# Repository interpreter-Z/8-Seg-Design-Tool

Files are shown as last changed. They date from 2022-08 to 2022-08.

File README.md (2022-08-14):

# 8-Seg-Design-Tool
A PCB click-toy that you can use to design 8-segment display patterns (or kill time with)

This repo houses a simple hardware project for a custom PCB designed with KiCad 6.0.

For more information on the following items, please refer to:
- Final product:      README.pdf
- PCB source files:   8 Seg Design Tool/
- Gerber files:       gerbers/
- Components:         datasheet/
- Purchase Links:     BOM.csv

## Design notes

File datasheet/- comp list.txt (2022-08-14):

8 Seg Display (38.10): 	https://www.digikey.com/en/products/detail/chromeled/CDSA15R1W/13166840
	      (20.32):	https://www.digikey.com/en/products/detail/kingbright/SA08-11EWA/3084462
Toggle Botton (SPST): 	https://www.digikey.com/en/products/detail/judco-manufacturing-inc/50-0015-00/307997
	      (DPST):	https://www.digikey.com/en/products/detail/c-k/PVA1EEH11-2NV2/417713
LED (15mcd):		https://www.digikey.com/en/products/detail/bivar-inc/SM1206HC/3095545
    (4.5mcd):		https://www.digikey.com/en/products/detail/osram-opto-semiconductors-inc/LS-L29K-G1J2-1-Z/1227979
Coin Cell Holder:	https://www.digikey.com/en/products/detail/mpd-memory-protection-devices/BH800S/221549
Coin Cell:		https://www.digikey.com/en/products/detail/murata-electronics/CR2025/9558424
Resistor:		https://www.digikey.com/en/products/detail/stackpole-electronics-inc/RMCF1206JT150R/1757485
Toggle Switches:	https://www.digikey.com/en/products/detail/nkk-switches/B13JB/4507647
PCB Connector:		https://www.digikey.com/en/products/detail/w%C3%BCrth-elektronik/613010143121/2508632

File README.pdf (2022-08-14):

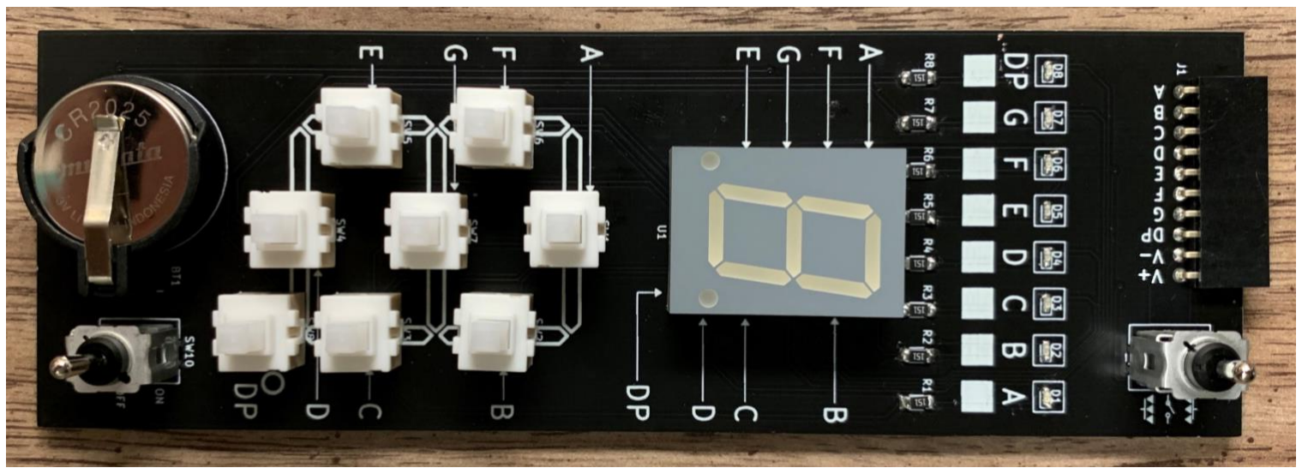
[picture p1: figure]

## facilitate design of 8-segment illumination pattern

(Or just a click-toy to kill time with)

# 8-Segment Display Design Tool

## Features:

Display: • LED x8 • 8-segment display x1

Display Control: • Toggle push switch (DPST) x8 • Switches are arranged to mirror 7-segment display pattern

(*or 8

-segment if you count the decimal)

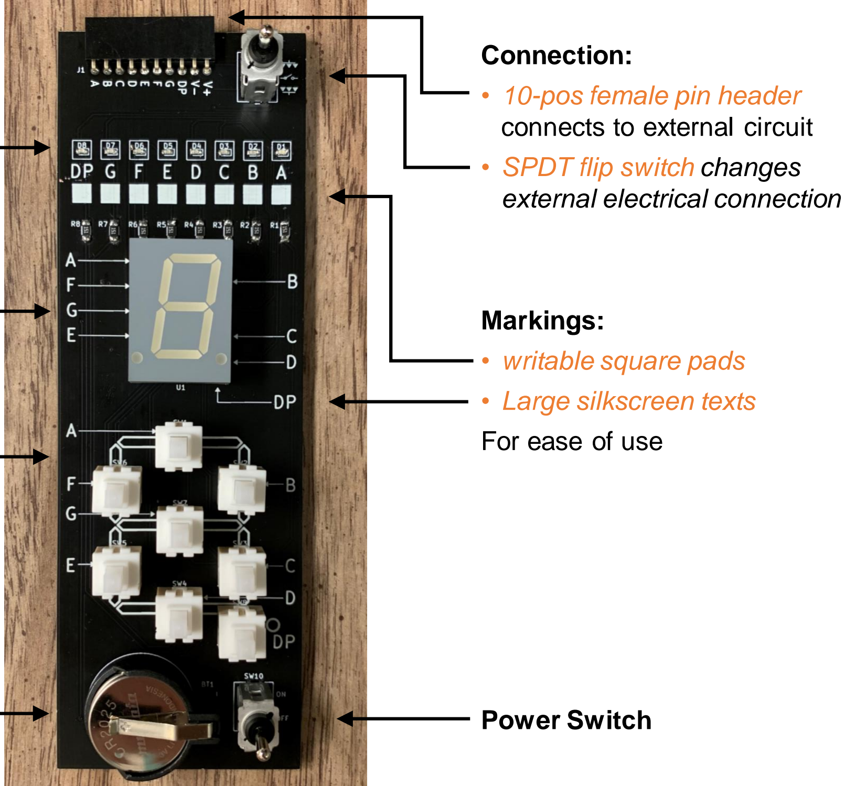
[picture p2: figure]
For ease of use; Connection: • 10-pos female pin header; connects to external circuit; • SPDT flip switch changes external electrical connection; Power Switch

Markings: • writable square pads • Large silkscreen texts

Power: • 3V Coin Cell x2 = 6V

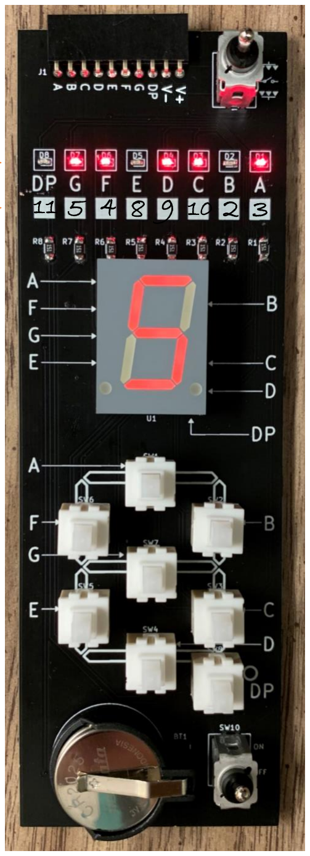
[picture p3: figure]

## Function 1: Map Segment to Pin

1. On the white squares, (using a marker,) write down the pinout of each segment of the display that is specific to your project
2. Press to toggle the push switches such that you see your desired pattern on the 8-segment display
3. Check the row of LED to have a quick view of which segments are illuminated. NOTE that the segment designators are sequenced from RIGHT TO LEFT
4. Find the pinout of the illuminated segments by referring to your notes on the white squares and program your project code accordingly. Depending on the complexity of your code, you might not need to do this step.

1

3
4

## Function 2: Switching External Display

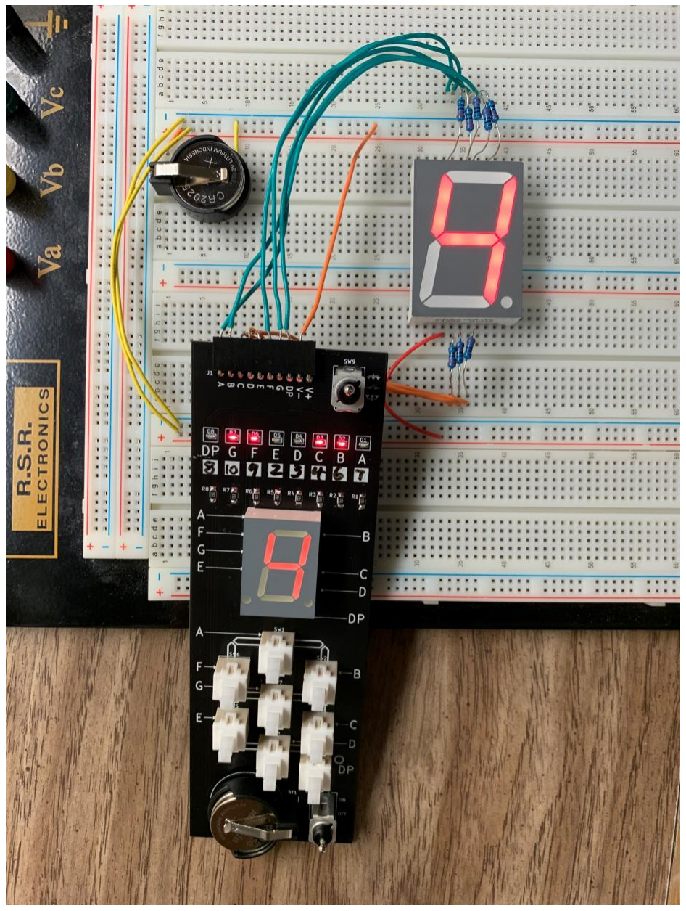
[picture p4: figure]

The PCB can be connected to an external display and power source to control that display (even when the PCB is powered off).

The external display is controlled the same way as the on-board display. NOTE that external resistors are required for the external display

On J1, connect the pins to their corresponding segments (A~G and DP) on the external display.

Depending on the type of external display, the external power supply need to be connected to the PCB in different ways.

## Function 2: Switching External Display (cont.)

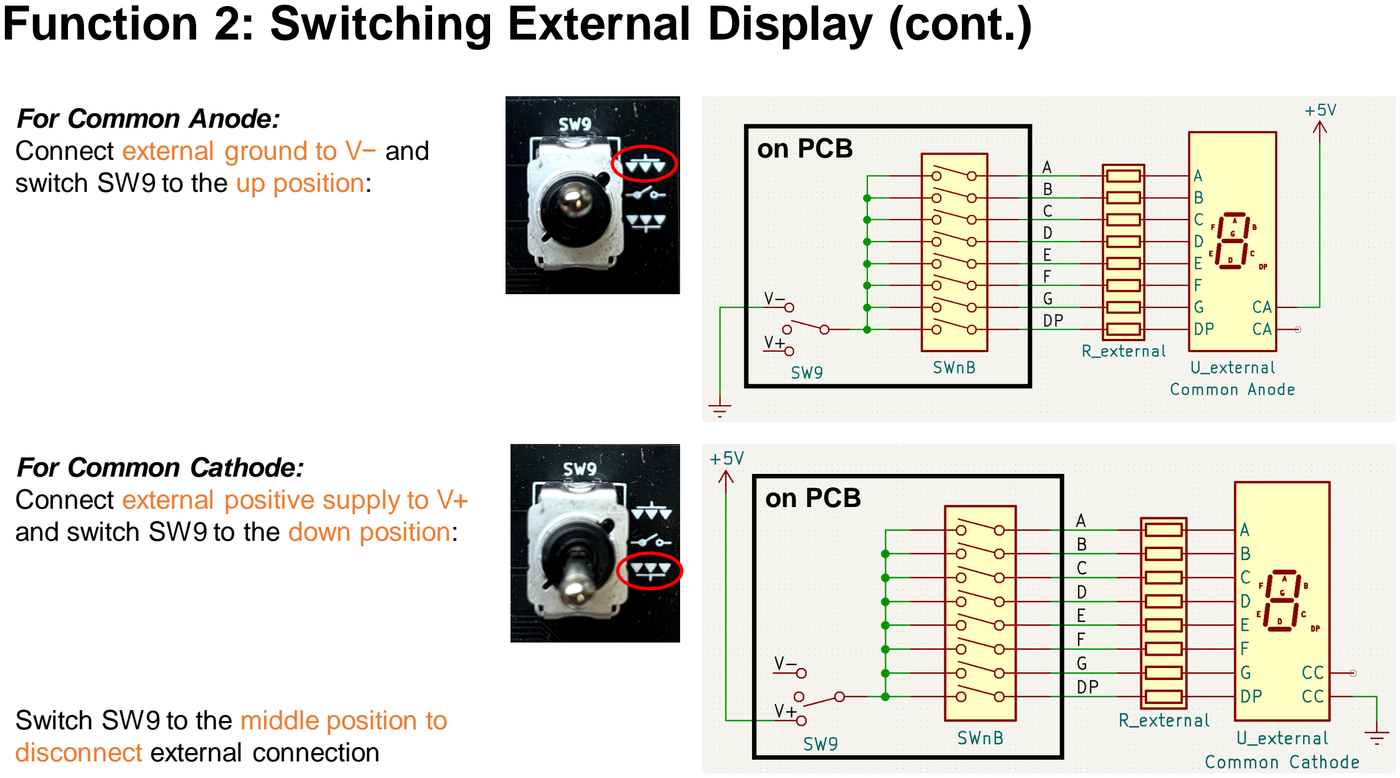
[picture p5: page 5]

on PCB

on PCB

For Common Anode:
Connect external ground to V− and switch SW9 to the up position:

For Common Cathode:
Connect external positive supply to V+ and switch SW9 to the down position:

Switch SW9 to the middle position to disconnect external connection

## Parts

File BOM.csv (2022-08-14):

Source: | D:\SPTS_A\MyWorks\KiCad\8 Seg Design Tool\8 Seg Design Tool\8 Seg Design Tool.kicad_sch
Date: | 6/13/2022 00:46
Tool: | Eeschema (6.0.0)
Generator: | D:\SPTS_B\Applications\KiCad\6.0\bin\scripting\plugins/bom_csv_grouped_by_value.py
Component Count: | 29
Collated Components:
Num Duplicates | 2 |  |  |  |  | (At 1 Dup) |  | (At Dup Qty)
Item | Qty | Dup Qty | Reference(s) | Value | MPN | Unit Price | Total Price | Unit Price | Total Price | URL
1 | 1 | 2 | BT1 | BH800S | BH800S | $1.41 | $1.41 | $1.41 | $2.82 | https://www.digikey.com/en/products/detail/mpd-memory-protection-devices/BH800S/221549
2 | 8 | 16 | D1, D2, D3, D4, D5, D6, D7, D8 | RED | LS L29K-G1J2-1-Z | $0.41 | $3.28 | $0.32 | $5.14 | https://www.digikey.com/en/products/detail/osram-opto-semiconductors-inc/LS-L29K-G1J2-1-Z/1227979
3 | 1 | 2 | J1 | Conn_01x10 | 6.1301E+11 | $0.95 | $0.95 | $0.95 | $1.90 | https://www.digikey.com/en/products/detail/w%C3%BCrth-elektronik/613010143121/2508632
4 | 8 | 16 | R1, R2, R3, R4, R5, R6, R7, R8 | 150 | RMCF1206JT150R | $0.10 | $0.80 | $0.03 | $0.45 | https://www.digikey.com/en/products/detail/stackpole-electronics-inc/RMCF1206JT150R/1757485
5 | 8 | 16 | SW1, SW2, SW3, SW4, SW5, SW6, SW7, SW8 | SW_DPST_x2 | PVA1EEH11.2NV2 | $1.65 | $13.20 | $1.48 | $23.63 | https://www.digikey.com/en/products/detail/c-k/PVA1EEH11-2NV2/417713
6 | 2 | 4 | SW9, SW10 | B13JB | B13JB | $4.92 | $9.84 | $4.92 | $19.68 | https://www.digikey.com/en/products/detail/nkk-switches/B13JB/4507647
7 | 1 | 2 | U1 | SA08-11EWA | CDSA15R1W | $2.98 | $2.98 | $2.98 | $5.96 | https://www.digikey.com/en/products/detail/chromeled/CDSA15R1W/13166840
8 | 1 | 10 | - | - | CR2025 | $0.32 | $0.32 | $0.26 | $2.64 | https://www.digikey.com/en/products/detail/murata-electronics/CR2025/9558424
 |  |  |  |  |  | Total: | $32.78 | Total: | $62.22

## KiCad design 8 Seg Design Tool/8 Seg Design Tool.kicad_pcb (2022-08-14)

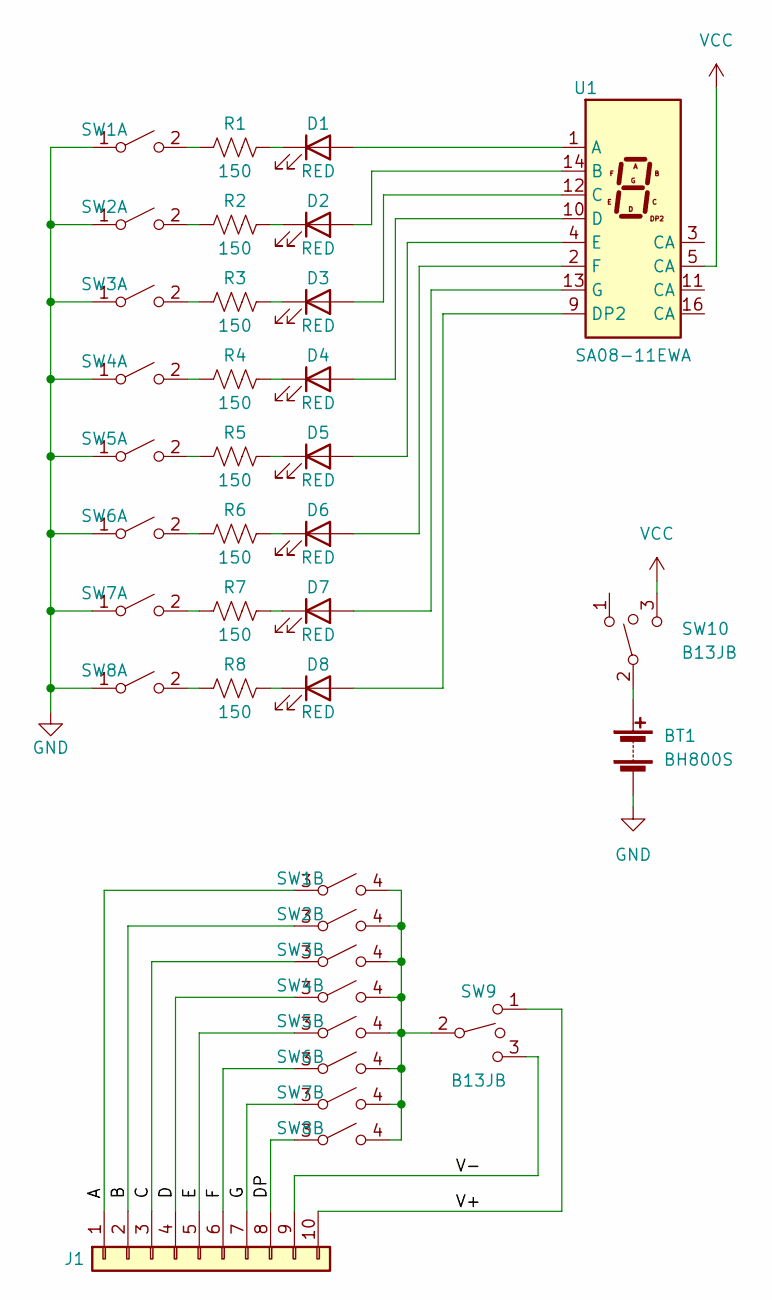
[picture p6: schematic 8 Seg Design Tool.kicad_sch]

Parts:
BT1: BH800S
D1, D2, D3, D4, D5, D6, D7, D8: RED; LS-L29K-G1J2-1-Z
J1: Conn_01x10; 613010143121
R1, R2, R3, R4, R5, R6, R7, R8: 150; RMCF1206JT150R
SW1, SW2, SW3, SW4, SW5, SW6, SW7, SW8: SW_DPST_x2; PVA1EEH11-2NV2-PDIP
SW9, SW10: B13JB
U1: SA08-11EWA; SA08-11EWA-PDIP

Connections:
GND: BT1.2 (-), SW1.1 (A), SW2.1 (A), SW3.1 (A), SW4.1 (A), SW5.1 (A), SW6.1 (A), SW7.1 (A), SW8.1 (A)
unnamed: BT1.1 (+), SW10.2 (B)
unnamed: D1.1 (K), R1.2
unnamed: D1.2 (A), U1.1 (A)
unnamed: D2.1 (K), R2.2
unnamed: D2.2 (A), U1.14 (B)
unnamed: D3.1 (K), R3.2
unnamed: D3.2 (A), U1.12 (C)
unnamed: D4.1 (K), R4.2
unnamed: D4.2 (A), U1.10 (D)
unnamed: D5.1 (K), R5.2
unnamed: D5.2 (A), U1.4 (E)
unnamed: D6.1 (K), R6.2
unnamed: D6.2 (A), U1.2 (F)
unnamed: D7.1 (K), R7.2
unnamed: D7.2 (A), U1.13 (G)
unnamed: D8.1 (K), R8.2
unnamed: D8.2 (A), U1.9 (DP2)
unnamed: J1.1, SW1.3 (A)
unnamed: J1.2, SW2.3 (A)
unnamed: J1.3, SW3.3 (A)
unnamed: J1.4, SW4.3 (A)
unnamed: J1.5, SW5.3 (A)
unnamed: J1.6, SW6.3 (A)
unnamed: J1.7, SW7.3 (A)
unnamed: J1.8, SW8.3 (A)
unnamed: J1.9, SW9.3 (C)
unnamed: J1.10, SW9.1 (A)
unnamed: R1.1, SW1.2 (B)
unnamed: R2.1, SW2.2 (B)
unnamed: R3.1, SW3.2 (B)
unnamed: R4.1, SW4.2 (B)
unnamed: R5.1, SW5.2 (B)
unnamed: R6.1, SW6.2 (B)
unnamed: R7.1, SW7.2 (B)
unnamed: R8.1, SW8.2 (B)
unnamed: SW1.4 (B), SW2.4 (B), SW3.4 (B), SW4.4 (B), SW5.4 (B), SW6.4 (B), SW7.4 (B), SW8.4 (B), SW9.2 (B)
VCC: SW10.3 (C), U1.5 (CC)

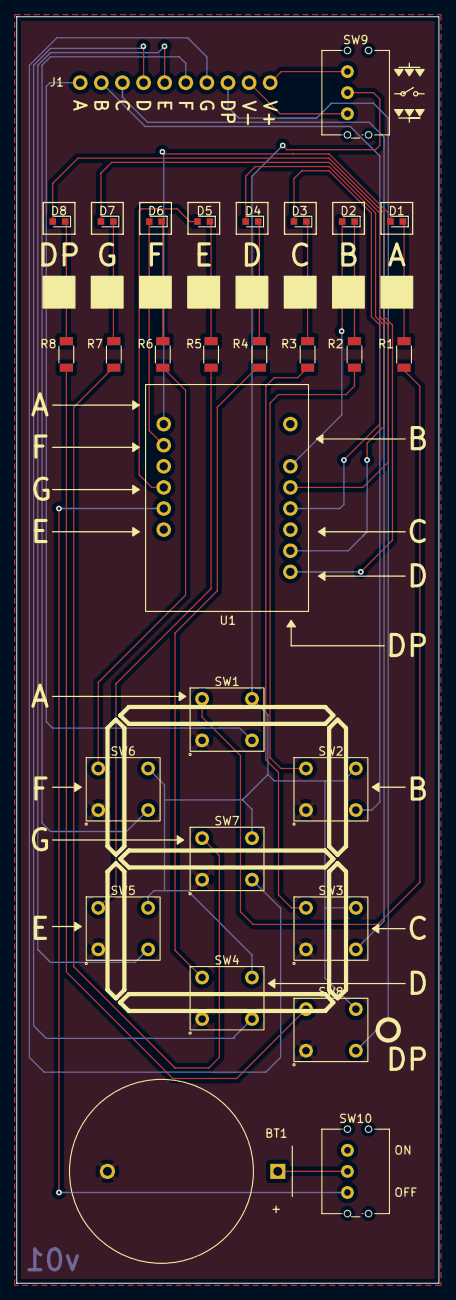
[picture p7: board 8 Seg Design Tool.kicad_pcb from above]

Board: 2 copper layers, 50.8 x 152.4 mm, 29 parts (0 on the bottom side), 38 nets.

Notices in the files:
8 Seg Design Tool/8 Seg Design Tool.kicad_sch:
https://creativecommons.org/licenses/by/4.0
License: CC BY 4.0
